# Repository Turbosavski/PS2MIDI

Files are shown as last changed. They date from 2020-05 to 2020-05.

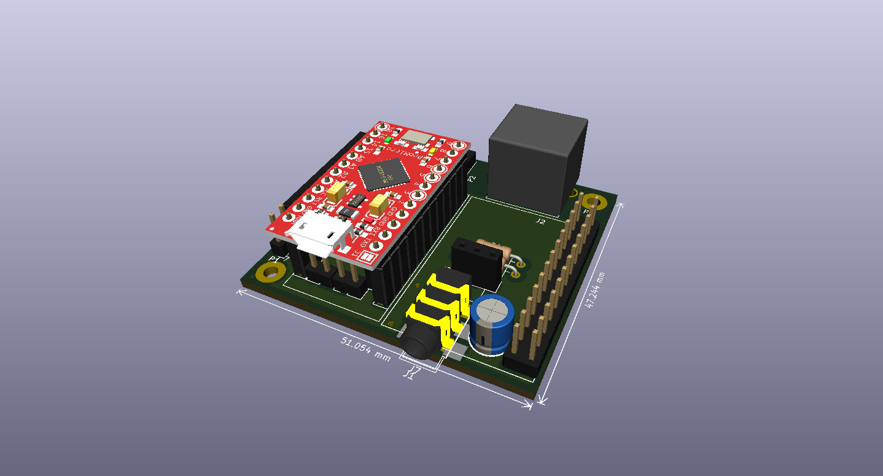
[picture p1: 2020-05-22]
PS2MIDI_1.png

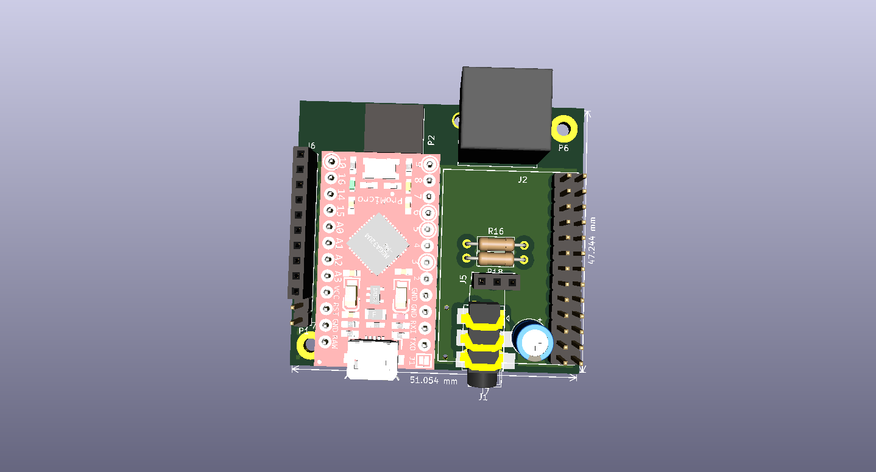
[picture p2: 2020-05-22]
PS2MIDI_2.png

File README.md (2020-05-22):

# PS2MIDI

PS/2 protocol and devices as midi interfaces: computer keyboard, mouse, touchpad

KiCad 5.1.5 files are provided for the small pcb board. For now existing / tested as a single sided prototypes for touchpad and computer keyboard. 

Previouly known as AI_SI Touchpad Piano (-> http://www.ljudmila.org/~savskib/?p=979). It is a midi trigger device based on a touchpad system found in any laptop computer – brought to a form of an oversimplified instrument that acts as (ahm...) piano. This module (-> https://www.serdashop.com/waveblaster) replaces the first version with Yamaha XG Midi daughter board (the 90s). My basic interest was just piano sounds.

The heart of the system is (of course) arduino. Arduino Promicro can be set as native usb device – so it was chosen (Sparkfun Pro micro 5V 16MHz version – a Chinese clone). An old laptop (sony vaio) provided a touchpad and parts to make the instrument housing. 

After the touchpad version an old ps/2 computer keyboard was used to some extent with adaptations to the relevant arduino library. Another option is of course the mouse - this would be probably very similar to touchpad. 

All these arduino sketches are available here in their latest development versions:
-> keyboardProMicro04
-> touchPadProMicro14

Quite some work was done in 2019 with adding the AI part on the level of three arduino libraries: midimelodics, midirhythmics and midistatistics - not yet finished but soon to be uploaded. Similar work is lately been done as a flute-like breath controller - but without the midi-synth.

Available here - in case the virus gets me...

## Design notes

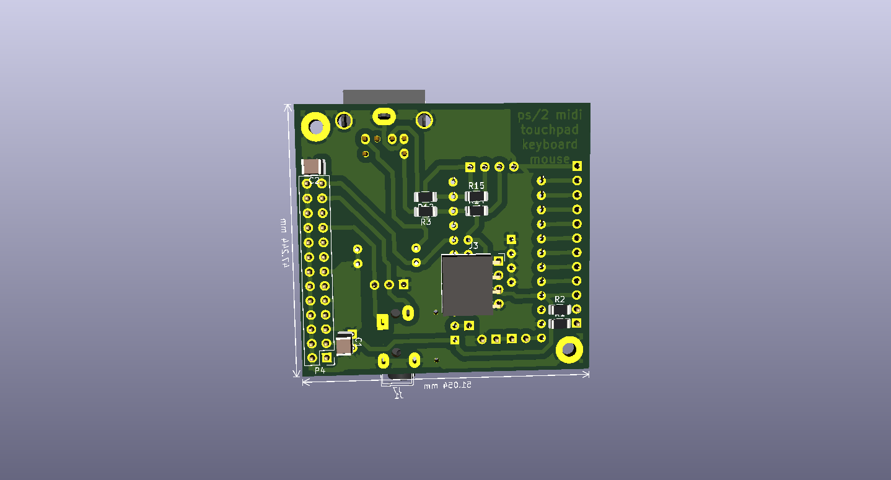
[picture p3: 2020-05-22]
PS2MIDI_6.png

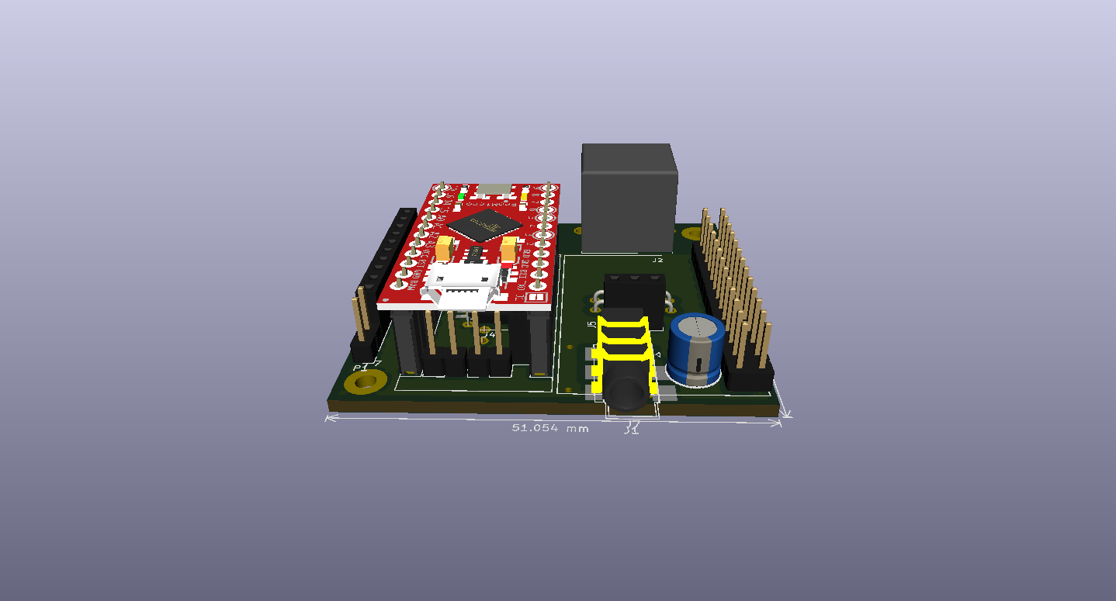
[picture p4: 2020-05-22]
PS2MIDI_3.png

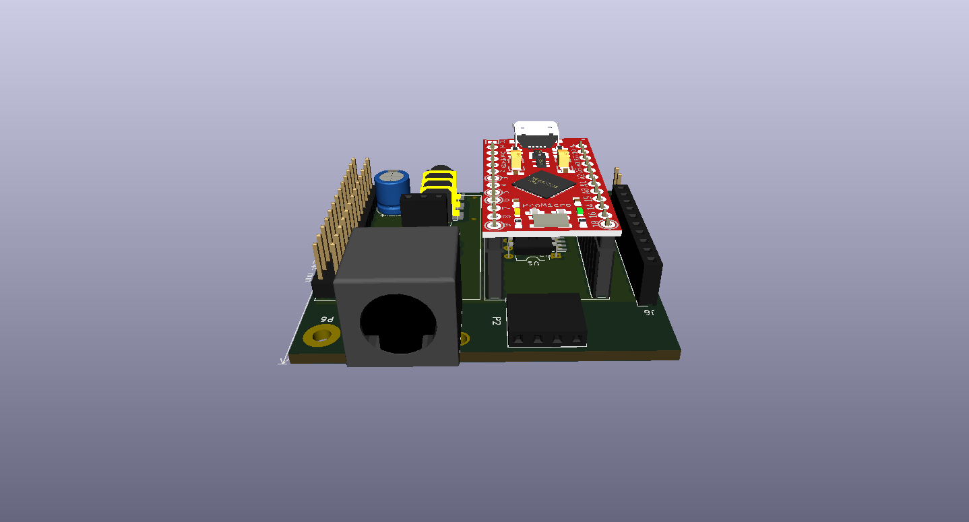
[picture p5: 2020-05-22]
PS2MIDI_5.png

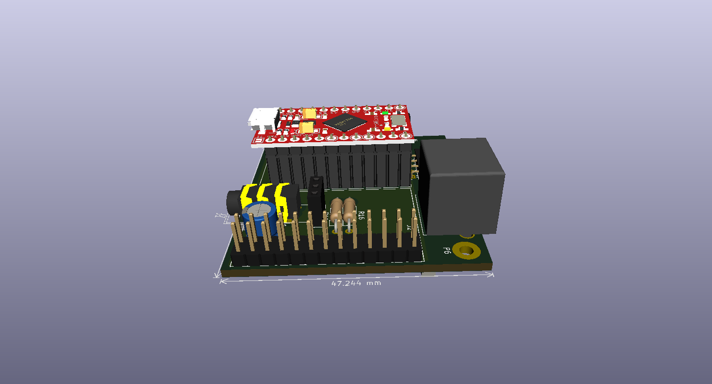
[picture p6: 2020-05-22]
PS2MIDI_4.png

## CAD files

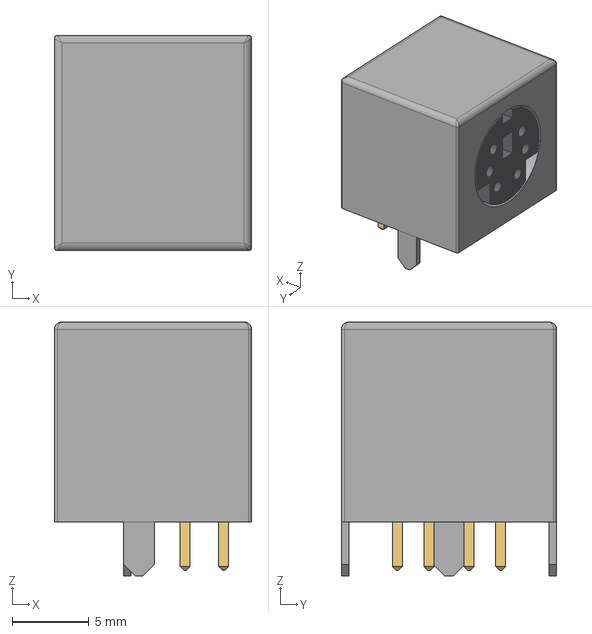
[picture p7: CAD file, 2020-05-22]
Mini-DIN-6P.step
12.8 x 14.0 x 16.5 mm

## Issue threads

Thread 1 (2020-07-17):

Arduino Leonardo

lmeucchi, 2020-07-17:
Hello, first thank you very much for sharing your code .... It seems that you spent a long time writing it, I could not understand many things jajaja but I want to do a test before putting it together.

I only have an arduino leonardo and a Synaptics TM-P2970 mousepad, is it possible to make it work without EEPROM and LCD?

I just have to change the connection pins on these lines?

#define PS2_CLK 6 // 5, touchpad ps / 2 clock pin T11
#define PS2_DATA 5 // 6, touchpad ps / 2 data pin T10

#define LEDPIN_RED 10 // red - for midi out traffic
#define LEDPIN_ORANGE 16 // orange to show AI selected
#define LEDPIN_GREEN 14 // green for device powered and status ok
#define MODEPIN 15 // switch live between SI and AI
#define MIDIPIN 18 // A0 // switch live between DIN and USB midi out

is there any video?

thank you

Turbosavski, 2020-07-20:
hi, eeprom and lcd are optional - not yet implemented (i think they are commented out in the code). You only need to connect the mousepad ps/2 wires - no leds / no switches. Left mousebutton acts as pedal, right mousebutton acts as chord - both pushed change the tonal scale (randomly). Should be no problem to test the whole code via usb. No video, since this is not a diy project. But there might soon be some audio album, since the prototype (acting as midi touchpad piano) is quite actively used. I think Leonardo and Promicro should have same pin definitions - but check anyway. SI mode is for now the only mode - meaning that tonal increments are from lowest notes on left-bottom and highest on top-right side of the touchpad. Quite some fun!

lmeucchi, 2020-07-22:
hi, how are you?
I connected my trackpad to arduino Leonardo, using pins 5 (data) and 6 (clock) ....

I changed this lines:
48 - bool usbmidi = false;
51 - bool midibaudrate = true;
`
by

48 - bool usbmidi = true;
51 - bool midibaudrate = false;

I also put a led to pin 10 for midi out traffic
When I touch the pad, the midi led turns on correctly, indicating that it is sending data, but the laptop does not receive midi messages (I tested it with MIDI-OX and Kontakt software).

Then change the above lines to send midi to DIN 5 ... that's when it started to work ... but the notes are sustained, when I touch the pad the notes are continuously sounding.
I tested the trackpad with a simple sketch to view PS/2 data with the serial monitor and it works correctly on all axes.

Another comment I want to tell you, my trackpad is a Synaptics TM-P2970 it has a single button on the pcb in the center, when you touch the pad in the lower left corner, the center button is operated and the pad recognizes that it is the left mouse button ... the same goes for the right side.
In the serial monitor that I told you previously, these changes also recognize them, but in your code via midi DIN 5 it does not work for me.
Thank you very much

Turbosavski, 2020-07-22:
The code is basically made for midi sound bank module, since my interest was only the piano sound. The midi communication in this case is via Tx pin (Serial1). Pro micro and Leonardo usb communication is defined as Serial. Apart from that you are pretty much on your own with this code & your hardware. My touchpad was from some sony vaio from around 2000. Cheers!

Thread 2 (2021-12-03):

Fast Read/Write

lmeucchi, 2021-12-03:
Hello, how are you ... I'm using the PS2 library to control a trackpad, after seeing your code I used some functions and settings to be able to send midi messages. It works very well but I needed more speed in reading the trackpad, that's why I made a test code to measure how many cycles per second the "PS2" and "PS2bs" library takes ... but I have no good news.

With Arduino Mega:
ps2:      112 Cycles per Second
ps2bs:  103 Cycles per Second

I wanted to know if there is something I am doing wrong, but the library "digitalWriteFast" does not allow to use constants and that is why it works in a normal "slow" way.

For the test code I use the files:
- ps2.h
- ps2.cpp
- digitalWriteFast.h
- ps2bs.h
- ps2bs.cpp

Here is the code, I use the two libraries at the same time but I choose each one in line 15 and 16
//PS2 mouse(MOUSE_CLOCK, MOUSE_DATA);  //  usage: PS2      mouse(int clk, int data)
PS2bs mouse(MOUSE_CLOCK, MOUSE_DATA);  //  usage: PS2bs  mouse(int clk, int data)

Thank you very much, regards

`
/*
 *
 *    ps2:    112 Cycles per Second
 *
 *    ps2bs:  103 Cycles per Second
 *
 */

#include "ps2.h"
#include "ps2bs.h"

#define MOUSE_DATA 15
#define MOUSE_CLOCK 14

//PS2 mouse(MOUSE_CLOCK, MOUSE_DATA);  //  usage: PS2      mouse(int clk, int data)
PS2bs mouse(MOUSE_CLOCK, MOUSE_DATA);  //  usage: PS2bs  mouse(int clk, int data)

int x = 0;
int y = 0;
int z = 0;

byte mstat1;
byte mstat2;
byte mxy;
byte mx;
byte my;
byte mz;

void setup()
{
  Serial.begin(115200);

  mouse_init();
}

void loop()
{

  Debug_Cycles_Per_Second ();

  mouse_read_loop ();

}

void Debug_Cycles_Per_Second ()
{
  static unsigned long cycles = 0;
  static unsigned long start = 0;
  static unsigned long current = 0;
  cycles++;
  current = millis();
  if (current - start >= 1000)
  {
    Serial.print("Cycles x Seg: ");
    Serial.println(cycles);
    cycles = 0;
    start = current;
  }
}

void mouse_read_loop ()
{
  mouse.write(0xeb);
  mouse.read();

  mstat1 = mouse.read();    //State 1     enable/disable    button on/off
  mxy = mouse.read();       //Both Axis
  mz = mouse.read();        //Pressure    finger pressure value
  mstat2 = mouse.read();    //State 2     different pad positions
  mx = mouse.read();        //Axis X      value
  my = mouse.read();        //Axis Y      value

  // collect the bits for x and y
  x = (((mstat2 & 0x10) << 8) | ((mxy & 0x0F) << 8) | mx );
  y = (((mstat2 & 0x20) << 7) | ((mxy & 0xF0) << 4) | my );
  z = mz;
}

void mouse_init()
{
  mouse.write(0xff);      // Reset
  mouse.read();           // Acknowledge byte      byte reconocimiento
  mouse.read();           // Blank */
  mouse.read();           // Blank */
  mouse.write(0xf0);      // Set Remote Mode
  mouse.read();           // Ack byte
  delayMicroseconds(100);
  mouse.write(0xe8);      // Set Resolution (argument 0-3)
  mouse.read();           // Ack byte
  mouse.write(0x03);      // x1  ( x1 * 64  +  x2 * 16  +  x3 * 4  +  x4   == modebyte )
  mouse.read();           // Ack byte
  mouse.write(0xe8);      // Set Resolution
  mouse.read();           // Ack byte
  mouse.write(0x00);      // x2
  mouse.read();           // Ack byte
  mouse.write(0xe8);      // Set Resolution
  mouse.read();           // Ack byte
  mouse.write(0x01);      // x3
  mouse.read();           // Ack byte
  mouse.write(0xe8);      // Set Resolution
  mouse.read();           // Ack byte
  mouse.write(0x00);      // x4
  mouse.read();           // Ack byte
  mouse.write(0xf3);      // Set Samplerate 20 (stores mode) (argument $00-$FF)
  mouse.read();           // Ack byte
  mouse.write(0x14);      // Samplerate Argument 20
  mouse.read();           // Ack byte
  delayMicroseconds(100);
}
`

Turbosavski, 2021-12-06:
Thanks for exhaustive comment! At the time i was also reaching out for speed - unsuccessfully it seems. But the machine is totally useful as it is - so i will drop the digitalWriteFast library for now.

With your comments and code i might look into it again - or you might?! But maybe the digitalRead(), pinMode() and digotalWrite() arduino functions are fast enough.

I think i remember also having some other issues regarding ps2.h library - and I somehow solved it with ps2bs.h

Cheers!

lmeucchi, 2021-12-10:
Hello
I've been looking for a solution, but I think it's impossible

I was able to reduce the time, adding this library "https://github.com/Locoduino/DIO2"
and i got these results:

ps2:           Total Loop duration 9020 µs
ps2bs:        Total Loop duration 9924 µs
ps2_Fast:    Total Loop duration 1568 µs

It is really fast, more than I expected.
But I don't know why, it can't read any value from the trackpad ...
I think that the ps2 protocol cannot be handled as fast as it can with the DIO2 library.

The simplest solution was to go back and use the original ps2 library, but creating two functions ...

The first one, reads only 1 bytes from the trackpad and compares it with a decimal value (in my case, 128 not pressed and 160 pressed)

The second, really when the trackpad is pressed (160 decimal)
Start reading all the bytes of the trackpad and send midi message

example:
```cpp
void TrackPad ()
{
  Trackpad.write(0xeb);        //Read Data
  Trackpad.read();

  mstat1 = Trackpad.read();    //State 1     enable/disable    button on/off

  // If the trackpad is pressed, then call the function to read all the full bytes
  if (mstat1 == 160)
  {
    TrackPad_Enable ();
  }
}

void TrackPad_Enable ()
{
  Trackpad.write(0xeb);        //Read Data
  Trackpad.read();

  mstat1 = Trackpad.read();    //State 1     enable/disable    button on/off
  mxy = Trackpad.read();       //Both Axis
  mz = Trackpad.read();        //Pressure    finger pressure value
  mstat2 = Trackpad.read();    //State 2     different pad positions
  mx = Trackpad.read();        //Axis X      value
  my = Trackpad.read();        //Axis Y      value

  // collect the bits for x and y
  x = (((mstat2 & 0x10) << 8) | ((mxy & 0x0F) << 8) | mx );
  y = (((mstat2 & 0x20) << 7) | ((mxy & 0xF0) << 4) | my );
  z = mz;

//do an action and send midi message

}
```

It is a simple but effective solution

Anyway, if you want to see how I modify the ps2 library, tell me and I'll share it here ..... read very quickly but it doesn't work

Thank you very much, regards

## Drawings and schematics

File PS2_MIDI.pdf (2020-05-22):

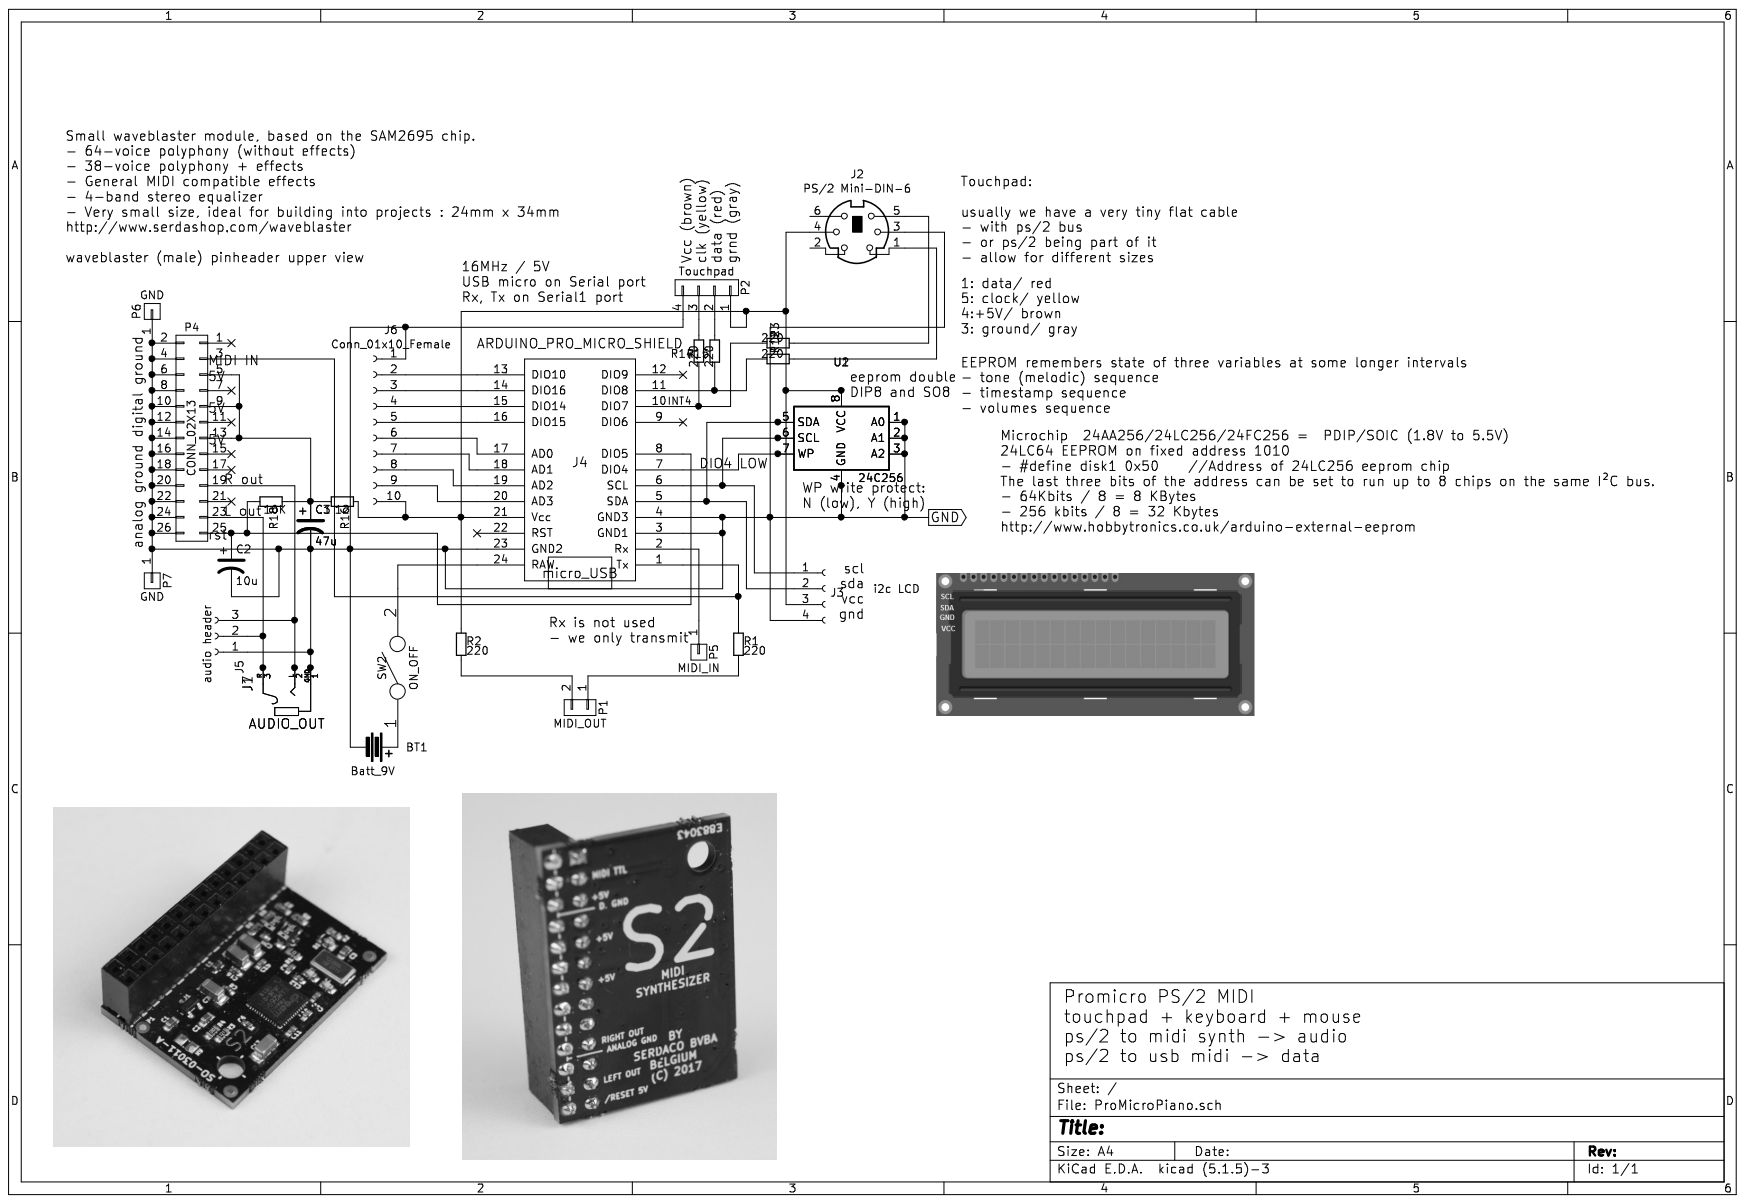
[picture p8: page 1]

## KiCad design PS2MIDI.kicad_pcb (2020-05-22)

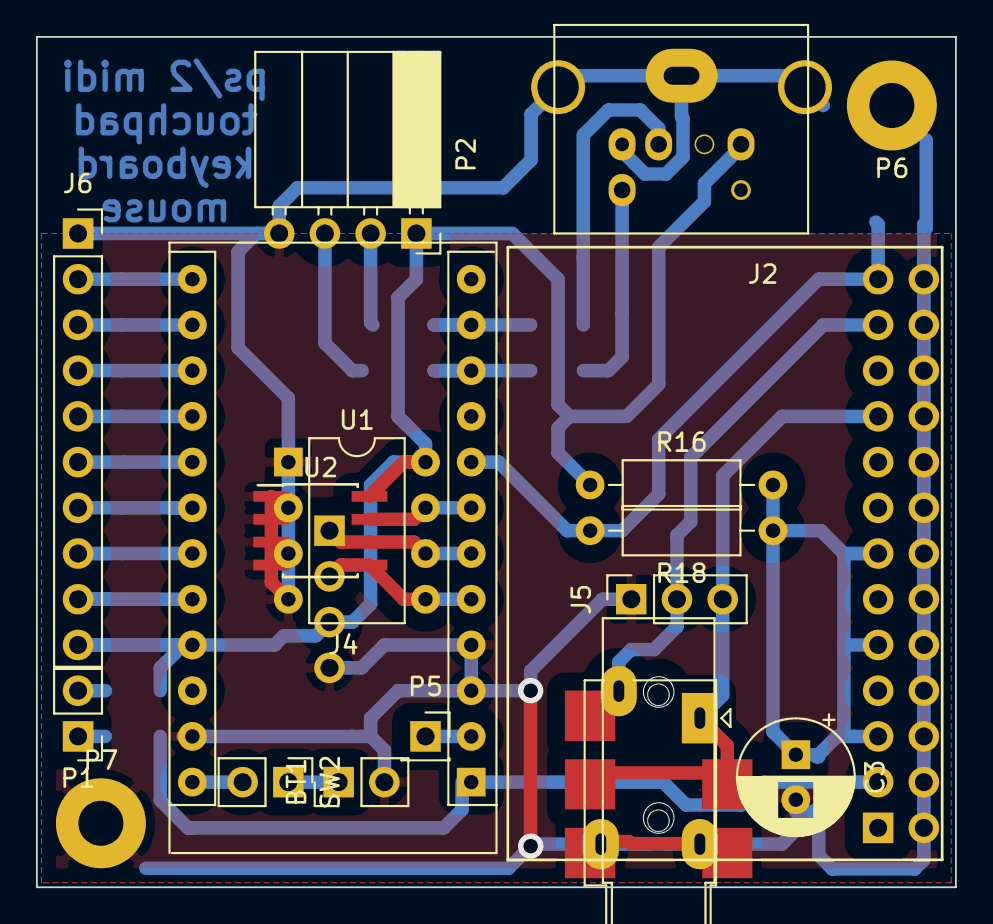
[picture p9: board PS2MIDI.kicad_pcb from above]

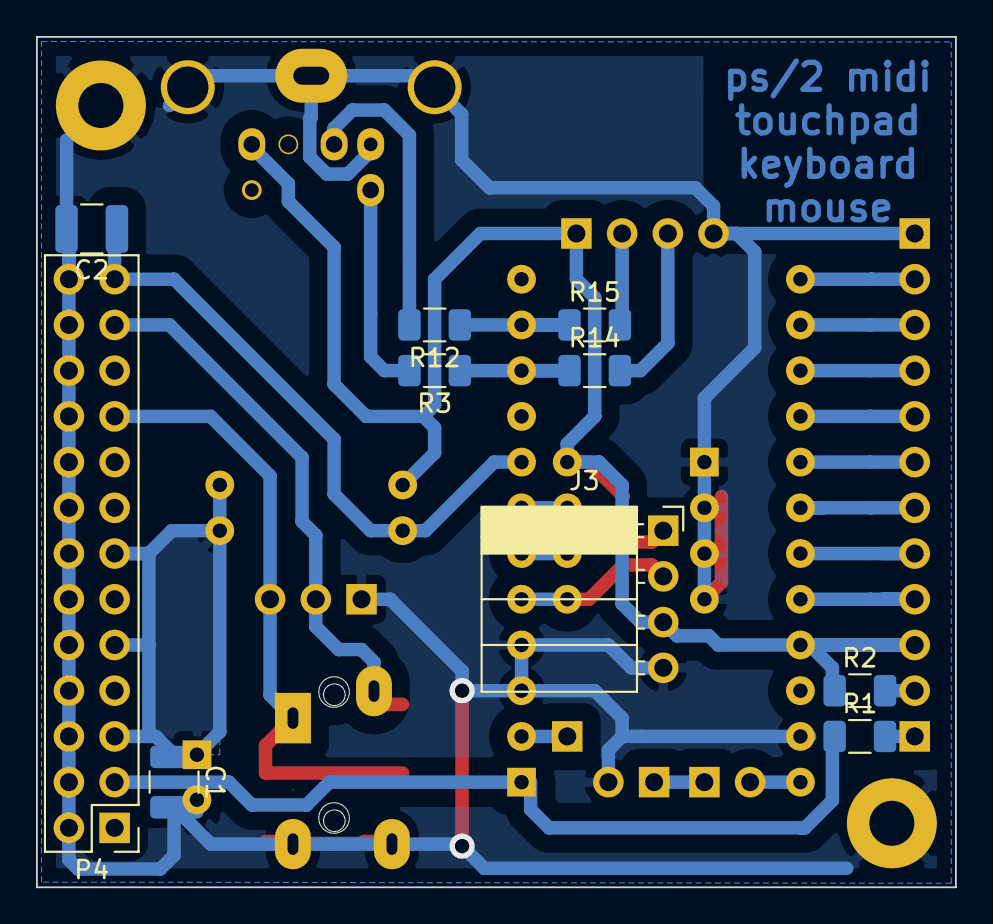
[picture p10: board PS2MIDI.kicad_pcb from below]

Board: 2 copper layers, 51.1 x 47.2 mm, 28 parts (10 on the bottom side), 29 nets.

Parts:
BT1: Batt_9V; PinHeader_1x02_P2.54mm_Vertical
C1: 47u; C_1210_3225Metric
C2: 10u; C_1210_3225Metric
C3: 47u; CP_Radial_D6.3mm_P2.50mm
J1: AUDIO_OUT; Jack_3.5mm_Horizontal_THT
J2: PS/2 Mini-DIN-6; MINI_DIN_Horizontal
J3: i2c LCD; PinSocket_1x04_P2.54mm_Horizontal
J4: ARDUINO_PRO_MICRO_SHIELD; Arduino_ProMicro
J5: audio header; PinSocket_1x03_P2.54mm_Vertical
J6: Conn_01x10_Female; PinSocket_1x10_P2.54mm_Vertical
J7: AUDIO_OUT; Jack_3.5mm_SMT_Horizontal
P1: MIDI_OUT; PinHeader_1x02_P2.54mm_Vertical
P2: Touchpad; PinSocket_1x04_P2.54mm_Horizontal
P4: CONN_02X13; PinHeader_2x13_P2.54mm_Vertical
P5: MIDI_IN; PinSocket_1x01_P2.54mm_Vertical
P6, P7: GND; MountingHole_2.5mm_Pad
R1, R2, R3, R12, R14, R15: 220; R_1206_3216Metric
R16: 12; R_Axial_DIN0207_L6.3mm_D2.5mm_P10.16mm_Horizontal
R18: 10K; R_Axial_DIN0207_L6.3mm_D2.5mm_P10.16mm_Horizontal
SW2: ON_OFF; PinHeader_1x02_P2.54mm_Vertical
U1: 24C256; DIP-8_W7.62mm
U2: 24C256; PowerIntegrations_SO-8

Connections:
GND: BT1.2, C1.2, C2.2, C3.2, J1.1, J2.3, J3.4, J4.3, J4.4, J4.23, J5.1, J6.1, J7.1, P2.4, P4.2, P4.4, P4.6, P4.8, P4.10, P4.12, P4.14, P4.16, P4.18, P4.20, P4.22, P4.24, P4.26, U1.1, U1.2, U1.3, U1.4, U2.1, U2.2, U2.3, U2.4
unnamed: BT1.1, SW2.1
unnamed: C1.1, C3.1, P4.5, P4.9, P4.13, R16.2, R18.1
unnamed: C2.1, J4.8, P4.25, R18.2
unnamed: J1.2, J5.3, J7.2, P4.19
unnamed: J1.3, J5.2, J7.3, P4.23
unnamed: J2.1, R12.2
unnamed: J2.4, J3.3, J4.21, J6.10, P2.1, R2.1, R16.1, U1.8, U2.8
unnamed: J2.5, R3.2
unnamed: J3.1, J4.6, U1.6, U2.6
unnamed: J3.2, J4.5, U1.5, U2.5
unnamed: J4.1, P4.3, R1.1
unnamed: J4.2, P5.1
unnamed: J4.7, U1.7, U2.7
unnamed: J4.10, R3.1, R14.1
unnamed: J4.11, R12.1, R15.1
unnamed: J4.13, J6.2
unnamed: J4.14, J6.3
unnamed: J4.15, J6.4
unnamed: J4.16, J6.5
unnamed: J4.17, J6.6
unnamed: J4.18, J6.7
unnamed: J4.19, J6.8
unnamed: J4.20, J6.9
unnamed: J4.24, SW2.2
unnamed: P1.1, R1.2
unnamed: P1.2, R2.2
unnamed: P2.2, R15.2
unnamed: P2.3, R14.2

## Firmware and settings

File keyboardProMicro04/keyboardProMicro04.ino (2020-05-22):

/**
* Sparkfun Arduino Pro Micro 16MHz 5V
* PS2 KEYBOARD MIDI SYNTH
* usb midi and DIN midi out
* to use internally the DreamBlaster Synth S2 - just connect its MIDI IN to Tx pin 
* Dreamblaster S1 : http://www.serdashop.com/waveblaster
* have audio stereo output
* have psu jack (9V) or just use usb micro for 5V psu 
* internally - 9V battery connector
* 
* very large latency and slow on MIDI OUT when used with usb midi
* when used with usb midi - still freezes after some time 
* solution: do not use both at the same time: switch between DIN and usb
* 
 * The Pro Micro has five external interrupts, which allow you to instantly trigger a function when a pin 
 * goes either high or low (or both). If you attach an interrupt to an interrupt-enabled pin, you’ll need 
 * to know the specific interrupt that pin triggers: pin 3 maps to interrupt 0, pin 2 is interrupt 1, pin 
 * 0 is interrupt 2, pin 1 is interrupt 3, and pin 7 is interrupt 4.
**/


const bool test = true; //false true;
const bool testtone = false; //false true;

unsigned long testime = millis();

// switch between the two serial outputs
// since they have large latency together

// true to send usb midi -> Serial
bool usbmidi = false; //false true;

// true: send additional (classic=ttl) midi on hw -> Serial1
bool midibaudrate = true; //true or false

//uint8_t midiCH = 0; // midi channel
char midiCH = 0; // midi channel

// maybe have a pot to set this?
// finger area and xy movement check - affects scale slide
//unsigned int sensibility = 150; // 50 minimum, 200 optimum, 500 seems stable

// comment out if not used
//#define AI 1

// pins used - not used: 5 
// pins 2 and 3: SDA and SCL - to eeprom
#define WP_PIN 4 // eeprom WP pin always low to enable writing

//Make sure you have data and clock wires connected correctly. 
//Clock wire MUST be connected to an interrupt pin!

// include local ps2 keyboard library - adapted by BS
#include "PS2Keyboard.h"
// CLK and DATA are bidirectional “open-collector” signals; they are normally held at 
// high (+5V) level by a 5–10K pull-up resistor on the host (arduino)
// check correct data/clock connection - 6, 7 - on pcb 5 and 6 - can be reversed

#define PS2_DATA 6 // 6, touchpad ps/2 data pin
#define PS2_CLK 7 // 5, touchpad ps/2 clock pin // MUST be connected to interrupt pin! Pin 7 = INT4

PS2Keyboard keyboard;

// use this or not
#define LEDPIN_RED 10 // red  - for midi out traffic
#define LEDPIN_ORANGE 16 // orange to show AI selected
#define LEDPIN_GREEN 14 // green for device powered and status ok
#define MODEPIN 15 // switch live between SI and AI
#define MIDIPIN 18 // A0 // switch live between DIN and USB midi out

// globals
// global to hold touchpad z,x,y sensor data
unsigned int data[3];
// global to hold touchpad previous data
unsigned int prevdata[3];
// global to hold touchpad rendered midi data
byte midinote[3]; // holds note, velocity and timing 
byte prevmidinote[3]; // holds note, velocity and timing 
// timing should measure how long the finger is held on touchpad!
// to basic note we can attach additional notes - to make a chord
byte midichord[2]; // holds a number of added note values
byte prevmidichord[2]; // holds a number of added note values

// transposition 4 here means: 4 * 12 + note / first note is C1=12 -> C5=60
// this will be changed with some plus/ minus buttons
// do not go below 0!
byte transposition = 3;
// this will be changed with some plus/ minus buttons
// do not go below 48!
byte velocity = 96;

// tonality will simplify playing - reduce/ replace notes that are not used with those used
byte tonality = 0; // 1: C-minor, 2: C-major

// have notes remember button pushed (0->1) / button released (1->0)
byte button[32]={0,0,0,0,0,0,0,0,0,0,0,0,0,0,0,0,0,0,0,0,0,0,0,0,0,0,0,0,0,0,0,0};

bool iskeyrelease = false;

// this is from touchpadPiano

// remember touch as firsttouch true when starting tone
// and put to false of finger pressure drops below threshold
bool firsttouch = false;
bool lasttouch = false;
bool noteoff = true; // always use it on next note triggered - force it sooner with left button 
bool leftbutt = false;
bool rightbutt = false;
bool chord = false; // make a chord or not
bool slide = false; // sense that we have a slide movement
unsigned long notetime = millis();
byte preveventtime = notetime/1000; // remember as relative

// when registers fill up - start from zero or pop the first and add the last
// or change keys for all elements? Too much work?
// or remember current index and use this to find what is in the past:
// smaller indexes = near past <- current index -> higher indexes far past

// how many notes to remember
// fifo or some global counter/pointer - overwriting the current value in arrays
// shifting array values to the left?
const unsigned int numnotes = 127;
// register to remember sequence of events:
// separate lists with corresponding indexes:
uint8_t register_notes[numnotes];
uint8_t register_volumes[numnotes];
uint8_t register_times[numnotes]; 
// 1 here means 0.1 second, 127 means 12 seconds
// counter of events - fills indexes up to numnotes - then resets
unsigned int events=0;

unsigned long lastchangetime = millis();
unsigned long lastchangeinterval = 10000; // in ms = 10s

// this keeps synaptics touchpad and midi under control
// seems that midiusb crashes often
#define INTERVAL_LENGTH_US 75000UL  // microsecs = 50ms, 75ms or 100ms

unsigned long previousMicros;
//unsigned long previousMicros = INTERVAL_LENGTH_US;

// all these are local files

#include "midimusicality.h"
//instantiate an object in order to call its member functions
MidiMusicality Music;

// global to be changed
bool ai = false;
#ifdef AI
  #include "midistatistics.h"
#endif

// midi usb stuff - standard library
// allow to switch between the internal synth and usbmidi
#include <MIDIUSB.h>

byte mididata[] = {
  0, // 5th byte
  0, // 6th byte - channel index byte - channels 1-16 - or some other adress for effects
  0, // 7th byte - instrument group byte - index - or some other adress
  0  // 8th byte - instrument byte - index - or some other address or control value
};

//select instrument index from the list below
byte instrument = 0;

// find instrument data by instrument index
const int NUMBER_OF_VOICES = 46;
const byte instruments[NUMBER_OF_VOICES][2] PROGMEM = {
  {0,0},  // Grand Piano
  {0,2},  // Bright Piano
  {0,3}, // El. Grand Piano
  {0,4}, // Honky-tonk Piano
  {0,5}, // El. Piano 1 
  {0,6}, // El. Piano 2 
  {0,7}, // Harpsichord
  {0,8}, // Clavi
  {0,9}, // Celesta
  {0,10}, // Glockenspiel
  {0,11}, // Music Box
  {0,12}, // Vibraphone
  {0,13}, // Marimba
  {0,14}, // Xylophone
  {0,15}, // Tubular Bells
  {0,16}, // Santur
  {0,17}, // Drawbar Organ
  {0,25}, // Nylon Guitar
  {0,26}, // Steel Guitar
  {0,27}, // Jazz Guitar
  {0,32}, // Guitar Harmonics
  {0,33}, // Acoustic Bass
  {0,34}, // Finger Bass
  {0,35},  //Pick Bass
  {0,36},  //Fretless Bass
  {0,37}, // Slap Bass 1
  {0,41}, // "Violine"               
  {0,44}, // "Contrabass"            
  {0,46}, // "Pizzicato Strings"     
  {0,47}, // "Orchestral Harp"       
  {0,48}, // "Timpani"               
  {0,53}, // "Choir Aahs"            
  {0,54}, // "Voice Oohs"            
  {0,57}, // "Trumpet"               
  {0,58}, // "Trombone"              
  {0,59}, // "Tuba"                  
  {0,66}, // "Tenor Sax"             
  {0,71}, // "Basoon"                
  {0,72}, // "Clarinet"              
  {0,105}, // "Sitar"                 
  {0,107}, // "Shamisen"              
  {0,108}, // "Koto"                  
  {0,109}, // "Kalimba"               
  {0,116}, // "Woodblock"             
  {0,117}, // "Taiko Drum"            
  {0,119} // "Synth Drum"            
};
// get it like this:
//pgm_read_byte(&instruments[0][i])


// local lib - optional
//#include "Button.h"

int key; // char
int prevkey; //char

long calctempodelay = 0;
long tempodelay = 500;
long curtimestamp = 0;
long prevtimestamp = 0;
long lasttickstamp =0;
long wheelfactor = 6; // adjust this to modify the pulseperiod to tempo ratio (wheel radius), higher = faster
int  tickflag = 0; // indicate if time tick has passed

const int dreamblaster_enable_pin = 6;
int buttonState = 0; 
int prev_buttonState = 0; 

int enabledrumming = 0;
int enablebassline = 0;
int enablesynthline = 0;

long seq_poscnt = 0;
byte resonantchannel= 1;
byte channel1_prog = 54;
byte channel2_prog = 81;

byte bassvolume = 0x50;
byte drumvolume = 0x50;
byte synthvolume = 0x50;
byte leadvolume  = 0x70;

/**
#define _BASSDRUM_NOTE 0x24
#define _SNAREDRUM_NOTE 0x26
#define _CLOSEDHIHAT_NOTE 0x2A
#define _PEDALHIHAT_NOTE 0x2C
#define _OPENHIHAT_NOTE 0x2E
#define _CYMBAL_NOTE 0x31
#define _DRUMPRESS_STATUSCODE 0x99
#define _DRUMRELEASE_STATUSCODE 0x89
#define _SYNTHPRESS_STATUSCODE 0x90
#define _SYNTHRELEASE_STATUSCODE 0x80

void midiwrite(int cmd, int pitch, int velocity) {
  Serial.write(cmd);
  Serial.write(pitch);
  Serial.write(velocity);
}

void midiprogchange(int cmd, int prog) {
  Serial.write(cmd);
  Serial.write(prog);
}
**/

/**
void midisetup_sam2195_nrpn_send(int channel, int control1,int control2, int value){
   Serial.write((byte)(0xB0+channel));
   Serial.write(0x63);
   Serial.write((byte)control1);
   Serial.write(0x62);
   Serial.write((byte)control2);
   Serial.write(0x06);
   Serial.write((byte)value);
}
void midisetup_sam2195_sysexcfg_send(int channelprefix,int channel, int control, int value){
   Serial.write(0xF0);
   Serial.write(0x41);
   Serial.write(0x00);
   Serial.write(0x42);
   Serial.write(0x12);
   Serial.write(0x40);
   Serial.write((byte)(channelprefix*16+channel));   
   Serial.write((byte)control);
   Serial.write((byte)value);   
   Serial.write(0x00);   
   Serial.write(0xF7);   
}
void midisetup_sam2195_gsreset(void){
  midisetup_sam2195_sysexcfg_send(0,0,0x7F,0);
}
void setupvoices(void)
{
    midiprogchange(0xC0,channel1_prog);
    midiprogchange(0xC1,channel2_prog);
}
void stopallnotes(byte selection = 0){  
  if (selection == 0 || selection ==2){
      midiwrite(0x90, 52, 0x00); // switch off possible synth notes
      midiwrite(0x90, 40, 0x00); // switch off possible synth notes     
  }
  if (selection == 0 || selection ==1){
      midiwrite(0x91, 28, 0x00); // switch off possible bass notes
      midiwrite(0x91, 40, 0x00); // switch off possible bass notes           
      midiwrite(0x91, 52, 0x00); // switch off possible bass notes
      midiwrite(0x91, 64, 0x00); // switch off possible bass notes
  }
}

**/

/**
void timercallback()
{
  lasttickstamp = millis();
  Timer1.setPeriod(tempodelay * 1000);     
  tickflag = 1;
}
**/

/**
void SomeButtonPressHandler(Button& butt){  
 if(enabledrumming)
  {
    if(butt == button3) {
      enablebassline = enablebassline?0:1;
    }

  } else {
    
    if(butt == button3) {  
      midiwrite(0x99, _SNAREDRUM_NOTE, 0x65);   
    }
    if(butt == button4) {  
      midiwrite(0x99, _BASSDRUM_NOTE, 0x65);   
    }
  }
}

void SomeButtonReleaseHandler(Button& butt){
  if(enabledrumming) {
    //..
  } else {
   // ..
  }
}

void SomeButtonHoldHandler(Button& butt){
  if(butt==button4) {
     stopdrum(); 
  }
}

void PotControl(int potnr, int ctrlVal){
  if(potnr == 1) {
     //Serial.println(ctrlVal);
      midisetup_sam2195_nrpn_send(resonantchannel,0x01,0x20,(byte)ctrlVal); 
      //midiwrite(0xB0, 0x01,(byte) ctrlVal);  // modulation wheel
  }
   if(potnr == 2) {
     midisetup_sam2195_nrpn_send(resonantchannel,0x01,0x21,(byte)ctrlVal);  // set resonance for channel resonantchannel
  }
}

void ADC_handle(void){
  static int prevsensorVal1 = -1000;  
  static int prevsensorVal2 = -1000;
  if(pot1setup) {
    int sensorValue = analogRead(A4);
    int ctrlValue;
    if(abs(sensorValue-prevsensorVal1)>3) {
        // filter noise from adc input
        prevsensorVal1 = sensorValue;
        ctrlValue = sensorValue/8;
        PotControl(1,ctrlValue);
    }
  }
  if(pot2setup) {
    int sensorValue = analogRead(A2);
    int ctrlValue;
    if(abs(sensorValue-prevsensorVal2)>3) {
        // filter noise from adc input
        prevsensorVal2 = sensorValue;
        ctrlValue = sensorValue/8;
        PotControl(2,ctrlValue);
    }
  }
}

**/

/**
void OLDsetup() {
  Serial.begin(31250);
  analogReference(DEFAULT); 
  
  pinMode(dreamblaster_enable_pin ,OUTPUT);   // enable the dreamblaster module by pulling high /reset
  digitalWrite(dreamblaster_enable_pin, HIGH);
  delay(300);  // allow 500ms for the dreamblaster to boot
  midisetup_sam2195_gsreset();
  delay(500);  // allow 250 for gs reset

  keyboard.begin(DataPin, IRQpin);  // ps2 keyboard
  
  //midisetup_sam2195_sysexcfg_send(0x02,0x00,0x01,0x50);  // set mod wheel cutoff
  //midisetup_sam2195_sysexcfg_send(0x02,0x00,0x04,0x00);  // disable mod wheel pitch variation
  //midisetup_sam2195_sysexcfg_send(0x02,0x00,0x05,0x7F);  // set mod wheel tvf depth
  midisetup_sam2195_nrpn_send(resonantchannel,0x01,0x21,(byte)0x7F);  // set resonance for channel resonantchannel

  Timer1.attachInterrupt(timercallback);
  Timer1.initialize(tempodelay*1000);   
  
  button3.pressHandler(SomeButtonPressHandler);
  button3.releaseHandler(SomeButtonReleaseHandler);  
  button4.pressHandler(SomeButtonPressHandler);
  button4.releaseHandler(SomeButtonReleaseHandler);
  button4.holdHandler(SomeButtonHoldHandler,1000);
  
  setupvoices();
}
**/

void noteOn(uint8_t channel, uint8_t pitch, uint8_t velocity) {
  midiEventPacket_t noteOn = {0x09, 0x90 | channel, pitch, velocity};
  if(usbmidi) MidiUSB.sendMIDI(noteOn);
}
void noteOff(uint8_t channel, uint8_t pitch) {
  midiEventPacket_t noteOff = {0x08, 0x80 | channel, pitch, 0};
  if(usbmidi) MidiUSB.sendMIDI(noteOff);
}

void controlChange(uint8_t channel, uint8_t control, uint8_t value) {
  midiEventPacket_t event = {0x0B, 0xB0 | channel, control, value};
  if(usbmidi) MidiUSB.sendMIDI(event);
}

// Simple pseudo-random number generator
// Multiply-with-carry method invented by George Marsaglia.
// two initializers (not null) - or we always get the same
unsigned long m_w = 1;
unsigned long m_z = 2;

// pseudo random generator
unsigned long getRandom(){
    m_z = 36969L * (m_z & 65535L) + (m_z >> 16);
    m_w = 18000L * (m_w & 65535L) + (m_w >> 16);
    return (m_z << 16) + m_w;  // 32-bit result
}
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
void loop() {

  //if (keyboard.availablerel()) {
  if (keyboard.available()) {
    // read the next key
    //iskeyrelease = false; //false
    // this sends 
    //key = keyboard.readrel(iskeyrelease);   // this returns a note or some code
    // no need for key release?
    key = keyboard.read();   // this returns a note number or some code
    // here we get a rafal of numbers from the library - if button pushed longer 
    
    // if button not pushed - declare that this is a push
    // and do not allow any additional notes to be played - until button released
    if(test && key>0){
      Serial.print(" pressed ");   
      Serial.print(key);   
      Serial.print(" which is note ");   
      Serial.print(midinote[0]);   
      //Serial.print(" pushed or released ");   
      //Serial.print(button[key]);   
      Serial.println(" ");   
      testime = millis();
    }  
    
    //if(button[key]==0) button[key]=1; // was pushed - block this note until next time -> released
    //else  button[key]=0; // was released -> back to normal

    // do what we want from this key
    //keyboardHandler(key, iskeyrelease);

    // transposition 4 here means: 4 * 12 + note / C1=12 -> C5=60
    midinote[0]= transposition*12 + key;
    midinote[1]=velocity;

    // play the note when key below 28 - or above 11
    if(key<28 && key>11){  // && button[key]==0
      // play it
      // do not trigger additional notes - if same note held
      //if(button[key]==1) button[key]=0;

      //if(firsttouch && midinote[0]==prevmidinote[0]){
      //  noteoff = true; // we had the first touch already
      //}

      /**
      if(noteoff) {
        // key released - stop the note
        //noteOff(uint8_t channel, uint8_t pitch)
        noteOff(midiCH, midinote[0]); // USBMIDI
        // Flush the combined midiusb output
        if(usbmidi) MidiUSB.flush();
  
        if(midibaudrate){
          noteOffSend(0x80, (char)midinote[0]);
          //noteOffSend(0x90, (char)midinote[0]);
        
        }  
        noteoff = false;
        firsttouch = false;

      }
      **/

      // do something on the basis of data above and create a midinote
      //generateNote();    
  
      notetime = millis();
      // remember before changed
      prevmidinote[0] = midinote[0]; // note
      prevmidinote[1] = midinote[1]; // velocity
      prevmidinote[2] = midinote[2]; // timing - if needed
      
     if(usbmidi){
       noteOn(midiCH, midinote[0], midinote[1]); // USBMIDI
       // Flush the combined midiusb output
       MidiUSB.flush();
     }
    
      // duplicate on hw MIDIOUT
     if(midibaudrate){
        //send note on
        noteOnSend(0x90, (char)midinote[0], (char)midinote[1]);
        //Serial1.flush(); //clears the buffer once all outgoing characters have been sent
     } 
     // register the note played
     //if(button[key]==0) button[key]=1;

        
    } else {
      
      // some other key: 1 to 11 or above 28
      
      //#define M_TRANSPOSE_M  1
      //#define M_TRANSPOSE_P  2 
      //#define M_VOLUME_M     3
      //#define M_VOLUME_P     4
      
      if(key==1 && transposition>1){
        transposition--;   // minus 1
      } 
      if(key==2 && transposition<7){
        transposition++;   // plus 1  
      } 
      if(key==3 && velocity>48){
        velocity-=12;   // minus 12 - have some larger interval
      } 
      if(key==4 && velocity<121){
        velocity+=12;   // plus 12 - have some larger interval
      } 
      // limits
      if(velocity<48)  velocity=48;
      if(velocity>127)  velocity=127;
     
    } // play the note

  } // keyboard available
  

  // seems usbmidi goes to sleep after some time
  // send noteoff every ten secs
  if(millis()-notetime>1000){
    notetime = millis();
    noteOff(midiCH, midinote[0]);
    // Flush the output
    if(usbmidi) MidiUSB.flush();
  }

 
}

void keyboardHandler(char key, bool iskeyrelease){
  static bool space_pressed = false;  
  static bool enter_pressed = false;  
  static bool zero_pressed = false;  
  static bool c_pressed = false;  
  static bool v_pressed = false;  
  static bool b_pressed = false;  

  if((key==PS2_PAGEUP)|| (key==PS2_PAGEDOWN) || (key=='+')|| (key=='-'))
  {
    if(!iskeyrelease) 
     {
        if(key=='+') 
        {
          channel2_prog++;
          if(channel2_prog > 0x7F)
          {
            channel2_prog = 0x00; 
          }       
        } 
       if(key=='-') 
        {
          channel2_prog--;
          if(channel2_prog > 0x7F)
          {
            channel2_prog = 0x7F; 
          }       
        } 
       if(key==PS2_PAGEUP) 
        {
          channel1_prog++;
          if(channel1_prog > 0x7F)
          {
            channel1_prog = 0x00; 
          }       
        } 
       if(key==PS2_PAGEDOWN)
        {
          channel1_prog--;
          if(channel1_prog > 0x7F)
          {
            channel1_prog = 0x7F; 
          }       
        } 

       //setupvoices();
     }
  }
  if(key==' ') 
   {
     if(!space_pressed || iskeyrelease) 
     {     
        //midiwrite(drumstatuscode, _BASSDRUM_NOTE, volumecode);      
     }
     space_pressed = !iskeyrelease;
     return;
   }
  if(key==PS2_ENTER) 
   {
     if(!enter_pressed  || iskeyrelease) 
     { 
      //midiwrite(drumstatuscode,_CLOSEDHIHAT_NOTE, volumecode); 
     }
     enter_pressed = !iskeyrelease;
     return;
   }
  if(key=='0') 
   {
     if(!zero_pressed || iskeyrelease) 
     { 
      //midiwrite(drumstatuscode,  _SNAREDRUM_NOTE, volumecode);      
     }
     zero_pressed = !iskeyrelease;
     return;
   }
   if(key=='c') 
   {
     if(!c_pressed || iskeyrelease) 
     { 
      //midiwrite(synthstatuscode,  40, volumecode);      
     }
     c_pressed = !iskeyrelease;
     return;
   }
   if(key=='v') 
   {
     if(!v_pressed || iskeyrelease) 
     { 
      //midiwrite(synthstatuscode,  45, volumecode);      
     }
     v_pressed = !iskeyrelease;
     return;
   }
   
   if(key=='b') 
   {
     if(!b_pressed || iskeyrelease) 
     { 
      //midiwrite(synthstatuscode,  50, volumecode);      
     }
     b_pressed = !iskeyrelease;
     return;
   }
   
   if(key=='1') 
   {
     if(!iskeyrelease) 
     {        
       buttonState = (buttonState==0) ? 1 : 0;        
     }
     return;
   }
   
   if(key=='2') 
   {
     if(!iskeyrelease) 
     { 
        //enablebassline = enablebassline?0:1;
        //if(!enablebassline) {stopallnotes(1);};
     }
     return;
   }
   
   if(key=='3') 
   {
     if(!iskeyrelease) 
     {        
       enabledrumming = (enabledrumming==0) ? 1 : 0;        
     }
     return;
   }
   
}

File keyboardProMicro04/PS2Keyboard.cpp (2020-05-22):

/*
  PS2Keyboard.cpp - PS2Keyboard library
  Copyright (c) 2007 Free Software Foundation.  All right reserved.
  Written by Christian Weichel <info@32leaves.net>

  ** Mostly rewritten Paul Stoffregen <paul@pjrc.com> 2010, 2011
  ** Modified for use beginning with Arduino 13 by L. Abraham Smith, <n3bah@microcompdesign.com> * 
  ** Modified for easy interrup pin assignement on method begin(datapin,irq_pin). Cuningan <cuninganreset@gmail.com> **

  for more information you can read the original wiki in arduino.cc
  at http://www.arduino.cc/playground/Main/PS2Keyboard
  or http://www.pjrc.com/teensy/td_libs_PS2Keyboard.html

  Version 2.4 (March 2013)
  - Support Teensy 3.0, Arduino Due, Arduino Leonardo & other boards
  - French keyboard layout, David Chochoi, tchoyyfr at yahoo dot fr

  Version 2.3 (October 2011)
  - Minor bugs fixed

  Version 2.2 (August 2011)
  - Support non-US keyboards - thanks to Rainer Bruch for a German keyboard :)

  Version 2.1 (May 2011)
  - timeout to recover from misaligned input
  - compatibility with Arduino "new-extension" branch
  - TODO: send function, proposed by Scott Penrose, scooterda at me dot com

  Version 2.0 (June 2010)
  - Buffering added, many scan codes can be captured without data loss
    if your sketch is busy doing other work
  - Shift keys supported, completely rewritten scan code to ascii
  - Slow linear search replaced with fast indexed table lookups
  - Support for Teensy, Arduino Mega, and Sanguino added

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
  You should have received a copy of the GNU Lesser General Public
  License along with this library; if not, write to the Free Software
  Foundation, Inc., 51 Franklin St, Fifth Floor, Boston, MA  02110-1301  USA
*/

#include "PS2Keyboard.h"

// BS
// Private function declarations
uint8_t PS2_led_lock = 0;     // LED and Lock status
int16_t send_next( void );
void set_lock( );
// end BS

#define BUFFER_SIZE 45
static volatile uint8_t buffer[BUFFER_SIZE];
static volatile uint8_t head, tail;
static uint8_t DataPin;
static uint8_t CharBuffer=0;
static bool CharBufferRelease=false;
static uint8_t UTF8next=0;
static const PS2Keymap_t *keymap=NULL;

// The ISR for the external interrupt
void ps2interrupt(void) {
  static uint8_t bitcount=0;
  static uint8_t incoming=0;
  static uint32_t prev_ms=0;
  uint32_t now_ms;
  uint8_t n, val;

  val = digitalRead(DataPin);
  now_ms = millis();
  if (now_ms - prev_ms > 250) {
    bitcount = 0;
    incoming = 0;
  }
  prev_ms = now_ms;
  n = bitcount - 1;
  if (n <= 7) {
    incoming |= (val << n);
  }
  bitcount++;
  if (bitcount == 11) {
    uint8_t i = head + 1;
    if (i >= BUFFER_SIZE) i = 0;
    if (i != tail) {
      buffer[i] = incoming;
      head = i;
    }
    bitcount = 0;
    incoming = 0;
  }
}

static inline uint8_t get_scan_code(void){
  uint8_t c, i;

  i = tail;
  if (i == head) return 0;
  i++;
  if (i >= BUFFER_SIZE) i = 0;
  c = buffer[i];

  tail = i;

  //Serial.print(" buffer ");
  //Serial.print(i);
  //Serial.print(" ");
  //Serial.println(c);

  // for each button push there is trio:
  //        i
  // buffer 0 51
  // buffer 1 240
  // buffer 2 51
  // repeating button:
  // buffer 3 51
  // buffer 4 240
  // buffer 5 51

  // if there is no 240 between numbers in buffer code 
  // and next number is the same as previous in the buffer
  // we should return nothing
  // this is against rafal of numbers / notes
  //if(buffer[i]!=240 && buffer[i-1]!=240) return 0;
  if(buffer[i]==buffer[i-1] && buffer[i-2]!=240) return 0;

  return c;
}

// http://www.quadibloc.com/comp/scan.htm
// http://www.computer-engineering.org/ps2keyboard/scancodes2.html

// These arrays provide a simple key map, to turn scan codes into ISO8859
// output.  If a non-US keyboard is used, these may need to be modified
// for the desired output.

// BS: some SI, DE letters are not defined in ISO8859! In such occasion return number
// MIDI keymap returns mostly numbers
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

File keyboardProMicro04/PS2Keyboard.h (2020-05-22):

/*
  PS2Keyboard.h - PS2Keyboard library
  Copyright (c) 2007 Free Software Foundation.  All right reserved.
  Written by Christian Weichel <info@32leaves.net>

  ** Mostly rewritten Paul Stoffregen <paul@pjrc.com>, June 2010
  ** Modified for use with Arduino 13 by L. Abraham Smith, <n3bah@microcompdesign.com> * 
  ** Modified for easy interrup pin assignement on method begin(datapin,irq_pin). Cuningan <cuninganreset@gmail.com> **

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
  You should have received a copy of the GNU Lesser General Public
  License along with this library; if not, write to the Free Software
  Foundation, Inc., 51 Franklin St, Fifth Floor, Boston, MA  02110-1301  USA
*/


#ifndef PS2Keyboard_h
#define PS2Keyboard_h

#if defined(ARDUINO) && ARDUINO >= 100
#include "Arduino.h" // for attachInterrupt, FALLING
#else
#include "WProgram.h"
#endif

#include "int_pins.h"

// Every call to read() returns a single byte for each keystroke.  
// These configure what byte will be returned for each "special" key. 
// To ignore a key, use zero.

//MIDI COMMANDS
#define M_TRANSPOSE_M  1
#define M_TRANSPOSE_P  2 
#define M_VOLUME_M     3
#define M_VOLUME_P     4

/* Ignore code for key code translation */
#define PS2_KEY_IGNORE  0xBB
#define PS2_KC_LOCK     0xED


// KEYBOARD COMMANDS

#define PS2_TAB        9
#define PS2_ENTER     13
#define PS2_BACKSPACE     127
#define PS2_ESC       27
#define PS2_INSERT      0
#define PS2_DELETE      127
#define PS2_HOME      0
#define PS2_END       0
#define PS2_PAGEUP      25
#define PS2_PAGEDOWN      26
#define PS2_UPARROW     11
#define PS2_LEFTARROW     8
#define PS2_DOWNARROW     10
#define PS2_RIGHTARROW      21
#define PS2_F1        0
#define PS2_F2        0
#define PS2_F3        0
#define PS2_F4        0
#define PS2_F5        0
#define PS2_F6        0
#define PS2_F7        0
#define PS2_F8        0
#define PS2_F9        0
#define PS2_F10       0
#define PS2_F11       0
#define PS2_F12       0
#define PS2_SCROLL    0

#define PS2_INVERTED_EXCLAMATION  161 // ¡
#define PS2_CENT_SIGN     162 // ¢
#define PS2_POUND_SIGN      163 // £
#define PS2_CURRENCY_SIGN   164 // ¤
#define PS2_YEN_SIGN      165 // ¥
#define PS2_BROKEN_BAR                  166 // ¦
#define PS2_SECTION_SIGN    167 // §
#define PS2_DIAERESIS     168 // ¨
#define PS2_COPYRIGHT_SIGN    169 // ©
#define PS2_FEMININE_ORDINAL    170 // ª
#define PS2_LEFT_DOUBLE_ANGLE_QUOTE 171 // «
#define PS2_NOT_SIGN      172 // ¬
#define PS2_HYPHEN      173
#define PS2_REGISTERED_SIGN   174 // ®
#define PS2_MACRON      175 // ¯
#define PS2_DEGREE_SIGN     176 // °
#define PS2_PLUS_MINUS_SIGN   177 // ±
#define PS2_SUPERSCRIPT_TWO   178 // ²
#define PS2_SUPERSCRIPT_THREE   179 // ³
#define PS2_ACUTE_ACCENT    180 // ´
#define PS2_MICRO_SIGN      181 // µ
#define PS2_PILCROW_SIGN    182 // ¶
#define PS2_MIDDLE_DOT      183 // ·
#define PS2_CEDILLA     184 // ¸
#define PS2_SUPERSCRIPT_ONE   185 // ¹
#define PS2_MASCULINE_ORDINAL   186 // º
#define PS2_RIGHT_DOUBLE_ANGLE_QUOTE  187 // »
#define PS2_FRACTION_ONE_QUARTER  188 // ¼
#define PS2_FRACTION_ONE_HALF   189 // ½
#define PS2_FRACTION_THREE_QUARTERS 190 // ¾
#define PS2_INVERTED_QUESTION MARK  191 // ¿
#define PS2_A_GRAVE     192 // À
#define PS2_A_ACUTE     193 // Á
#define PS2_A_CIRCUMFLEX    194 // Â
#define PS2_A_TILDE     195 // Ã
#define PS2_A_DIAERESIS     196 // Ä
#define PS2_A_RING_ABOVE    197 // Å
#define PS2_AE        198 // Æ
#define PS2_C_CEDILLA     199 // Ç
#define PS2_E_GRAVE     200 // È
#define PS2_E_ACUTE     201 // É
#define PS2_E_CIRCUMFLEX    202 // Ê
#define PS2_E_DIAERESIS     203 // Ë
#define PS2_I_GRAVE     204 // Ì
#define PS2_I_ACUTE     205 // Í
#define PS2_I_CIRCUMFLEX    206 // Î
#define PS2_I_DIAERESIS     207 // Ï
#define PS2_ETH       208 // Ð
#define PS2_N_TILDE     209 // Ñ
#define PS2_O_GRAVE     210 // Ò
#define PS2_O_ACUTE     211 // Ó
#define PS2_O_CIRCUMFLEX    212 // Ô
#define PS2_O_TILDE     213 // Õ
#define PS2_O_DIAERESIS     214 // Ö
#define PS2_MULTIPLICATION    215 // ×
#define PS2_O_STROKE      216 // Ø
#define PS2_U_GRAVE     217 // Ù
#define PS2_U_ACUTE     218 // Ú
#define PS2_U_CIRCUMFLEX    219 // Û
#define PS2_U_DIAERESIS     220 // Ü
#define PS2_Y_ACUTE     221 // Ý
#define PS2_THORN     222 // Þ
#define PS2_SHARP_S     223 // ß
#define PS2_a_GRAVE     224 // à
#define PS2_a_ACUTE     225 // á
#define PS2_a_CIRCUMFLEX    226 // â
#define PS2_a_TILDE     227 // ã
#define PS2_a_DIAERESIS     228 // ä
#define PS2_a_RING_ABOVE    229 // å
#define PS2_ae        230 // æ
#define PS2_c_CEDILLA     231 // ç
#define PS2_e_GRAVE     232 // è
#define PS2_e_ACUTE     233 // é
#define PS2_e_CIRCUMFLEX    234 // ê
#define PS2_e_DIAERESIS     235 // ë
#define PS2_i_GRAVE     236 // ì
#define PS2_i_ACUTE     237 // í
#define PS2_i_CIRCUMFLEX    238 // î
#define PS2_i_DIAERESIS     239 // ï
#define PS2_eth       240 // ð
#define PS2_n_TILDE     241 // ñ
#define PS2_o_GRAVE     242 // ò
#define PS2_o_ACUTE     243 // ó
#define PS2_o_CIRCUMFLEX    244 // ô
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
